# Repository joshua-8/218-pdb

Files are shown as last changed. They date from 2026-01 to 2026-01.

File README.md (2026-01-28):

# archived, moved to https://github.com/SPDLDaemon/SPDL-PDB

# Smart Product Design Lab - Power Distribution Board v2.1
## features
* 16 JST XH plugs with 3.3v ground and 5 volts
* 8 molex 254 plugs for servos

## user guide image
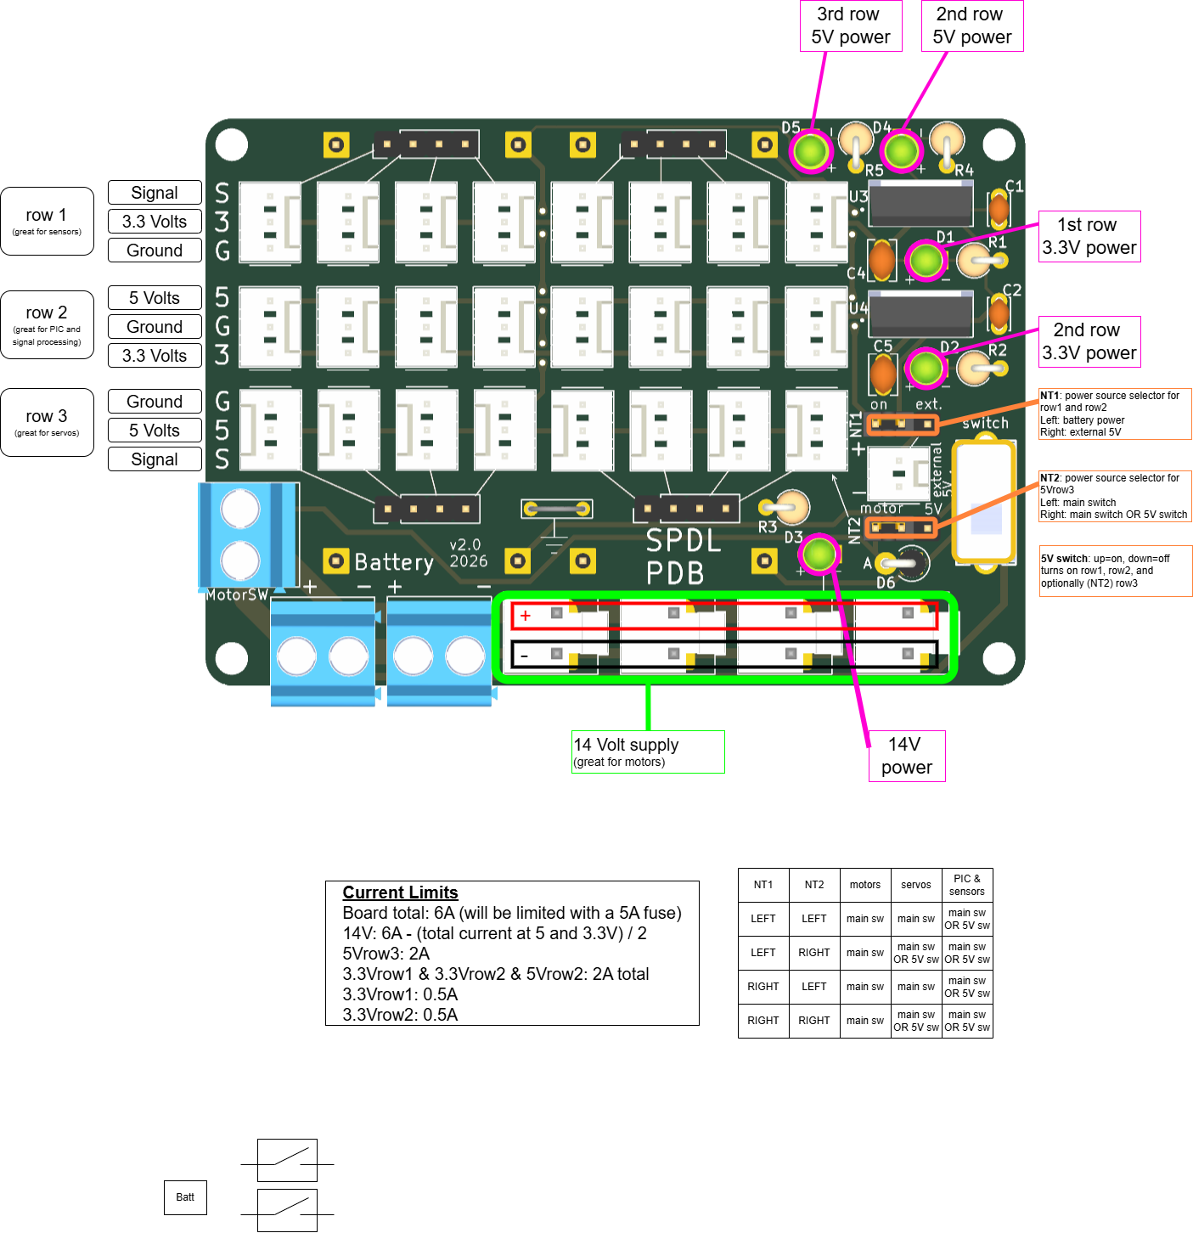
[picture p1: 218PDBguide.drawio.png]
218PDBguide

#### [link to user guide image](/218PDBguide.drawio.png)

### [link to schematic](/schematic.pdf)
### [link to image of PCB traces](/pcb.pdf)

## assembly
assembly guide coming soon

## images
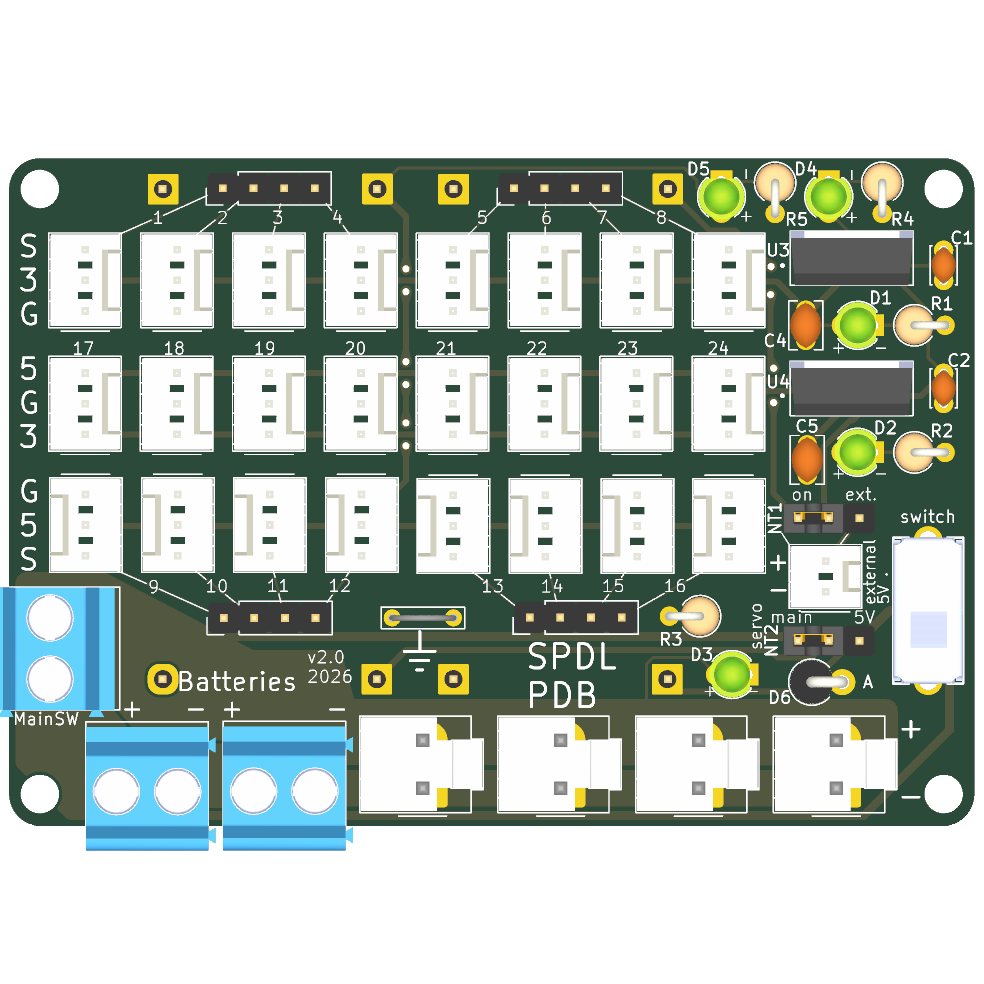
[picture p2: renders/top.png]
render of board

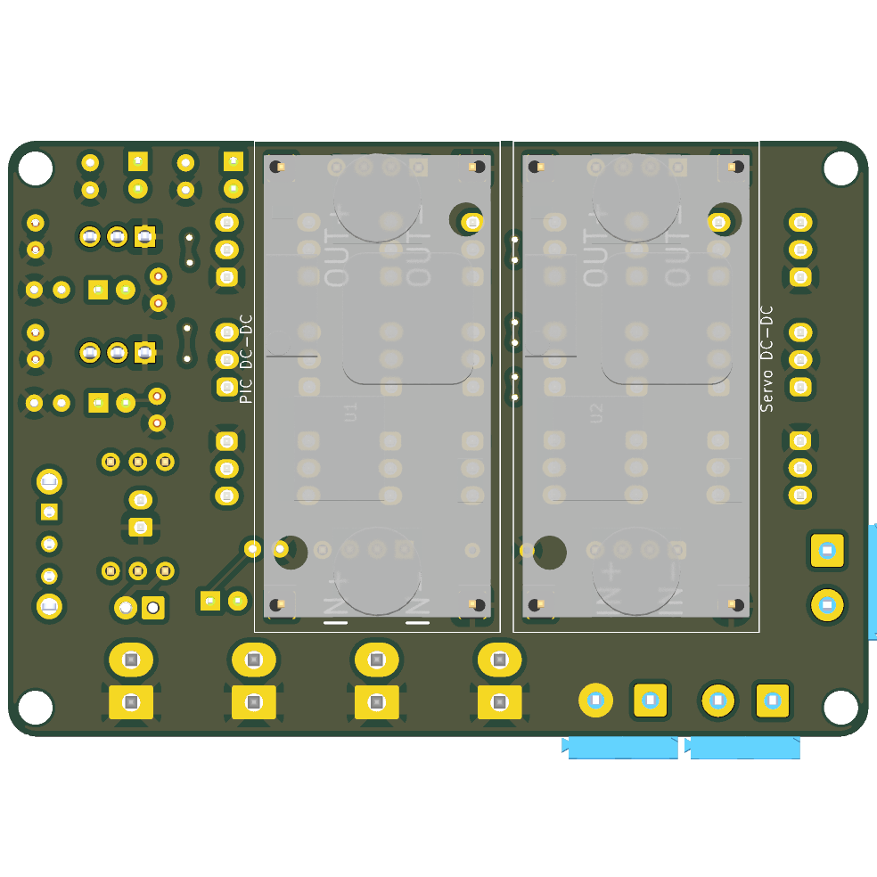
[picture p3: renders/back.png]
render of board back

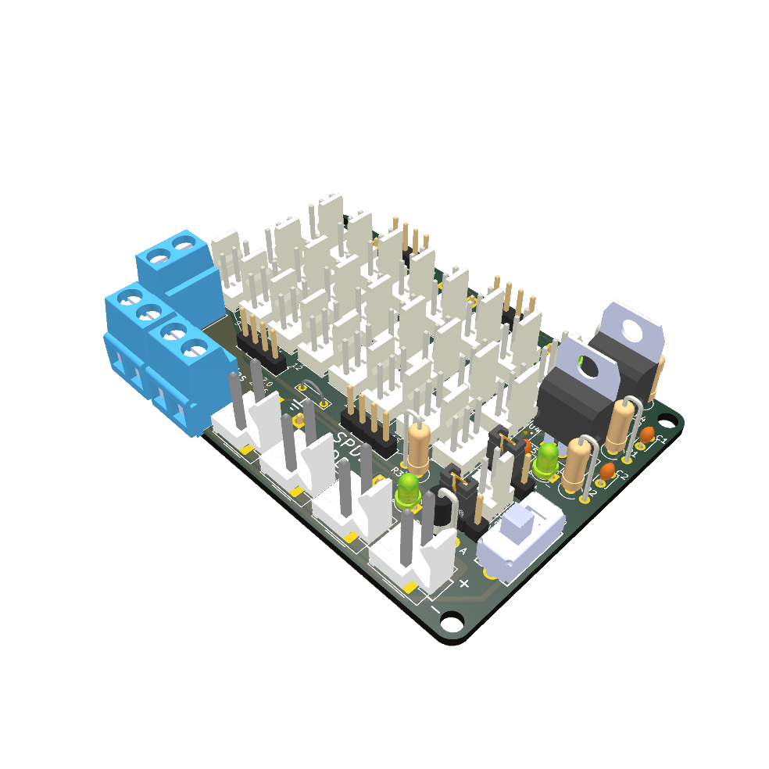
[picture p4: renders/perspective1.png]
render of board perspective1

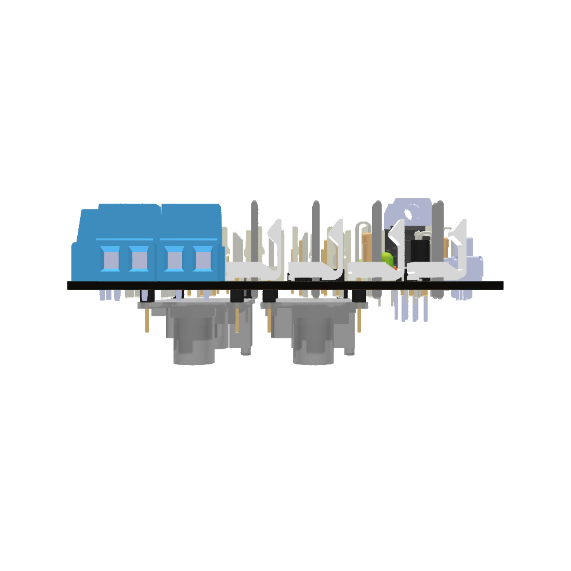
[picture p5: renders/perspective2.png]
render of board perspective2


## buying PCBs and components 
1x set of components from [bill of materials](/BOM.csv)

2x tamiya connectors for batteries (with wires)

1x main power switch

1x fuse holder (with wires) and fuse

1x PCB from ([gerber files](/gerbers.zip))

JST XH sockets (16)

JST XH crimps (48)

small flathead screwdriver

JST XH crimper

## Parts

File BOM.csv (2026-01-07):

Reference | Value | Footprint | Part_Number | QUANTITY
C1,C2 | 0.1 uF | Capacitor_THT:C_Disc_D3.0mm_W2.0mm_P2.50mm | 0.1 uF ceramic capacitor | 2
C4,C5 | 10 uF | Capacitor_THT:C_Disc_D3.8mm_W2.6mm_P2.50mm | 10uF tantalum (polarized) capacitor | 2
D1-D5 | LED | 218-pdb:LED_D3.0mm | 3 mm diameter LED | 5
D6 | diode, >=2 Amp | Diode_THT:D_DO-15_P2.54mm_Vertical_AnodeUp | >=2 Amp diode, e.g. Diotec 1N5060 | 1
FID1,FID2 | jumper | 218-pdb:jumper | pin jumper 0.1" pitch Sullins QPC02SXGN-RC | 2
FID3-FID10 | one header pin | 218-pdb:PinHeader_1x01_P2.54mm_Vertical | spdl, one header pin | 8
J1-J24 | Conn_01x03 | 218-pdb:Molex_KK-254_AE-6410-03A_1x03_P2.54mm_Vertical | 3 pin KK254 molex 0022232031 | 24
J25-J28 | Conn_01x04_Pin | Connector_PinHeader_2.54mm:PinHeader_1x04_P2.54mm_Vertical | 4 header pins 0.1" pitch | 4
J29-J32 | 14 V molex | 218-pdb:Molex_KK-396_A-41791-0002_1x02_P3.96mm_Vertical | 2 pin KK396 molex 0026604020 | 4
J33 | external 5V | 218-pdb:Molex_KK-254_AE-6410-02A_1x02_P2.54mm_Vertical | 2 pin KK 254 molex 0022232021 | 1
J34,J35 | battery | 218-pdb:CUI_TB007-508-02BE | screw terminal, 5.08" pitch, TB007-508-02BE | 2
main1 | MainSW | 218-pdb:CUI_TB007-508-02BE | screw terminal, 5.08" pitch, TB007-508-02BE | 1
NT1,NT2 | ~ | 218-pdb:PinHeader_1x03_P2.54mm_Vertical | 3 header pins 0.1" pitch | 2
R1,R2 | 680 | Resistor_THT:R_Axial_DIN0309_L9.0mm_D3.2mm_P2.54mm_Vertical | spdl | 2
R3 | 3.3k | Resistor_THT:R_Axial_DIN0309_L9.0mm_D3.2mm_P2.54mm_Vertical | spdl | 1
R4,R5 | 1k | Resistor_THT:R_Axial_DIN0309_L9.0mm_D3.2mm_P2.54mm_Vertical | spdl | 2
SW1 | 5V switch | 218-pdb:SLW-12689-4A-N-D | SLW-12689-4A-N-D | 1
TP1 | ground | TestPoint:TestPoint_Bridge_Pitch5.08mm_Drill0.7mm | piece of wire | 1
U1,U2 | DC-DC buck | 218-pdb:HW-411 | HW-411 lm2596 buck converter module | 2
U3,U4 | LD1117V33 | 218-pdb:TO255P1020X450X1968-3 | LD1117V33 | 2

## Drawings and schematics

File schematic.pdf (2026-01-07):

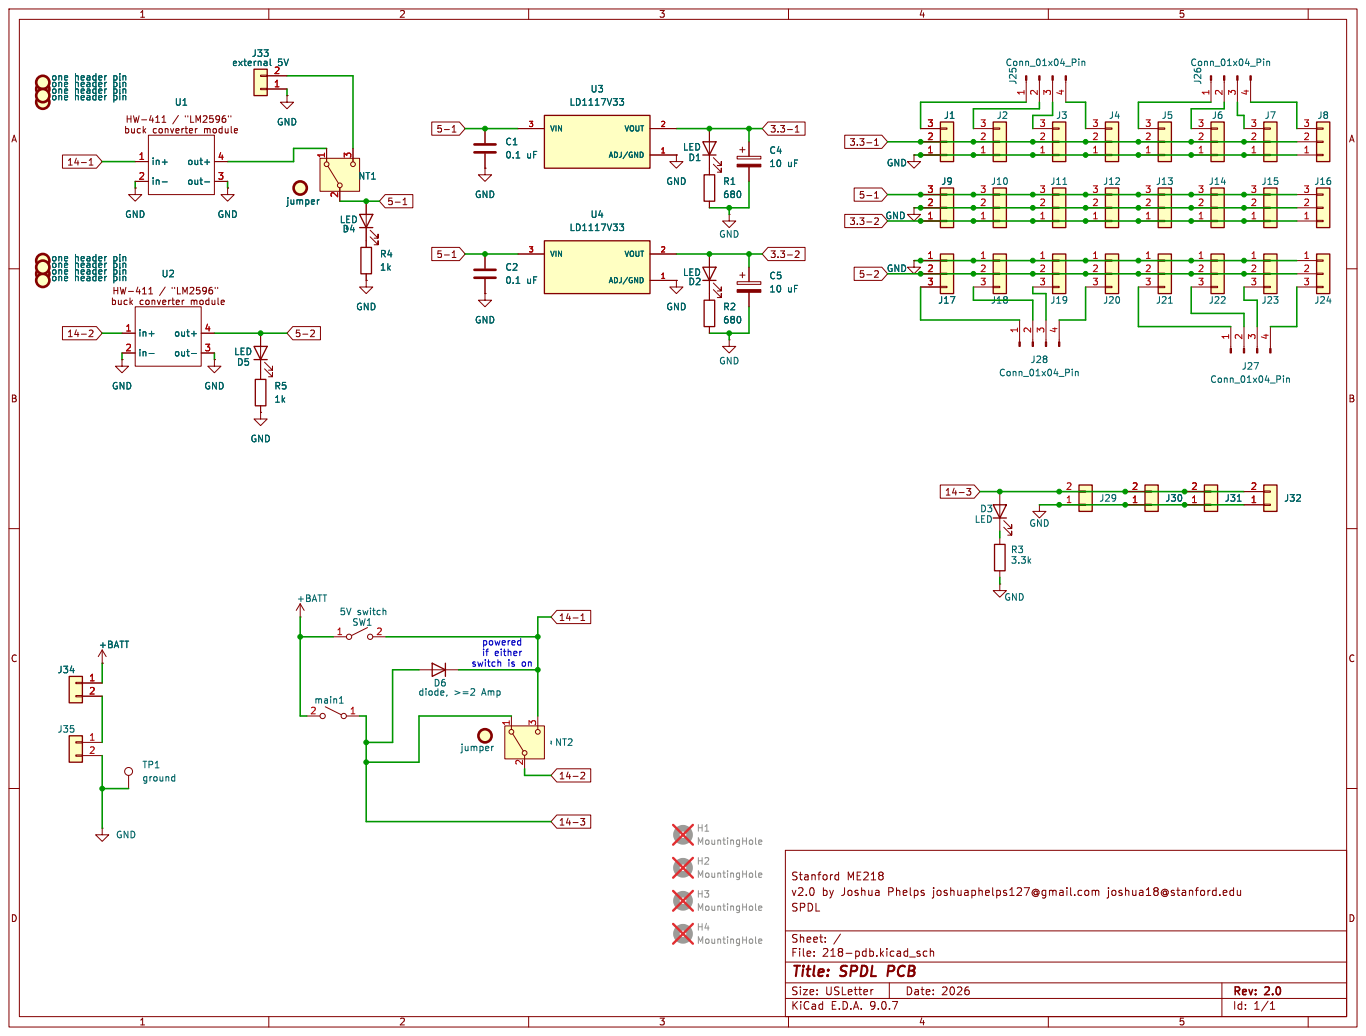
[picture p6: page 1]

powered
if either switch is on

v2.0 by Joshua File: 218-pdb.kicad_sch Sheet: / SPDL | ME218 | | Phelps joshuaphelps127@gmail.com | joshua18@stanford.edu Stanford

E.D.A. 9.0.7 Size: USLetter | | Rev: 2.0 | | | D Date: 2026 KiCad

Id: 1/1 Title: SPDL PCB

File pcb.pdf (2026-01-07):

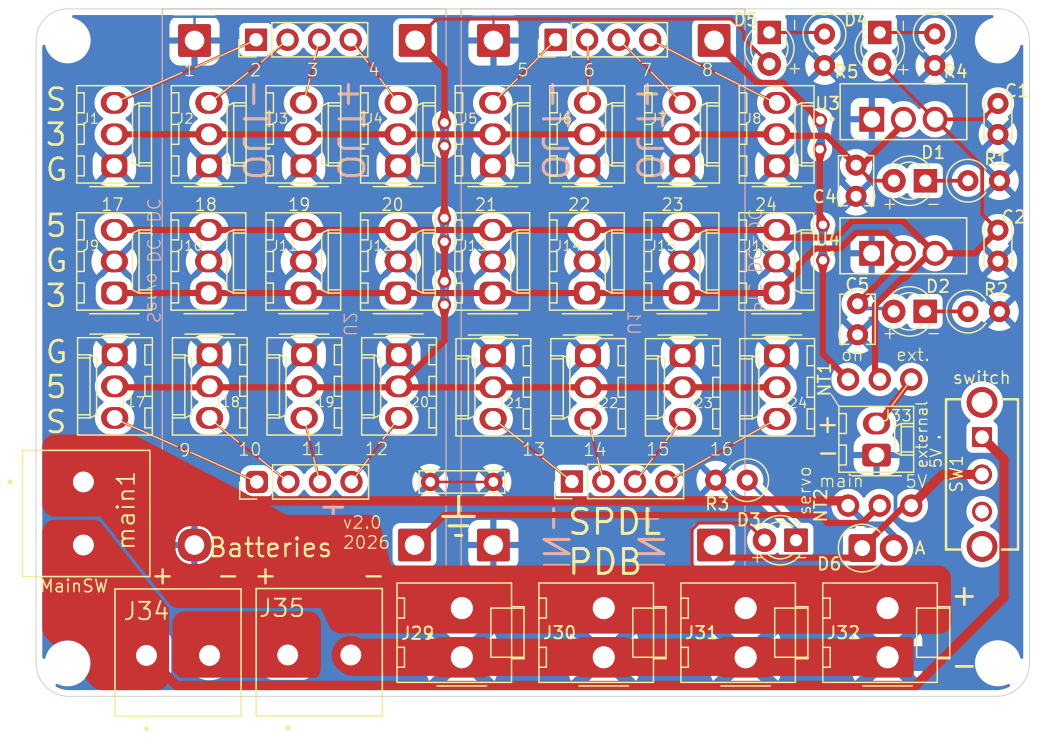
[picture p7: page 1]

PIC DC-DC Servo DC-DC U2 OUT- IN- IN+ OUT+ U1 OUT+ IN- IN+ OUT-

PDB

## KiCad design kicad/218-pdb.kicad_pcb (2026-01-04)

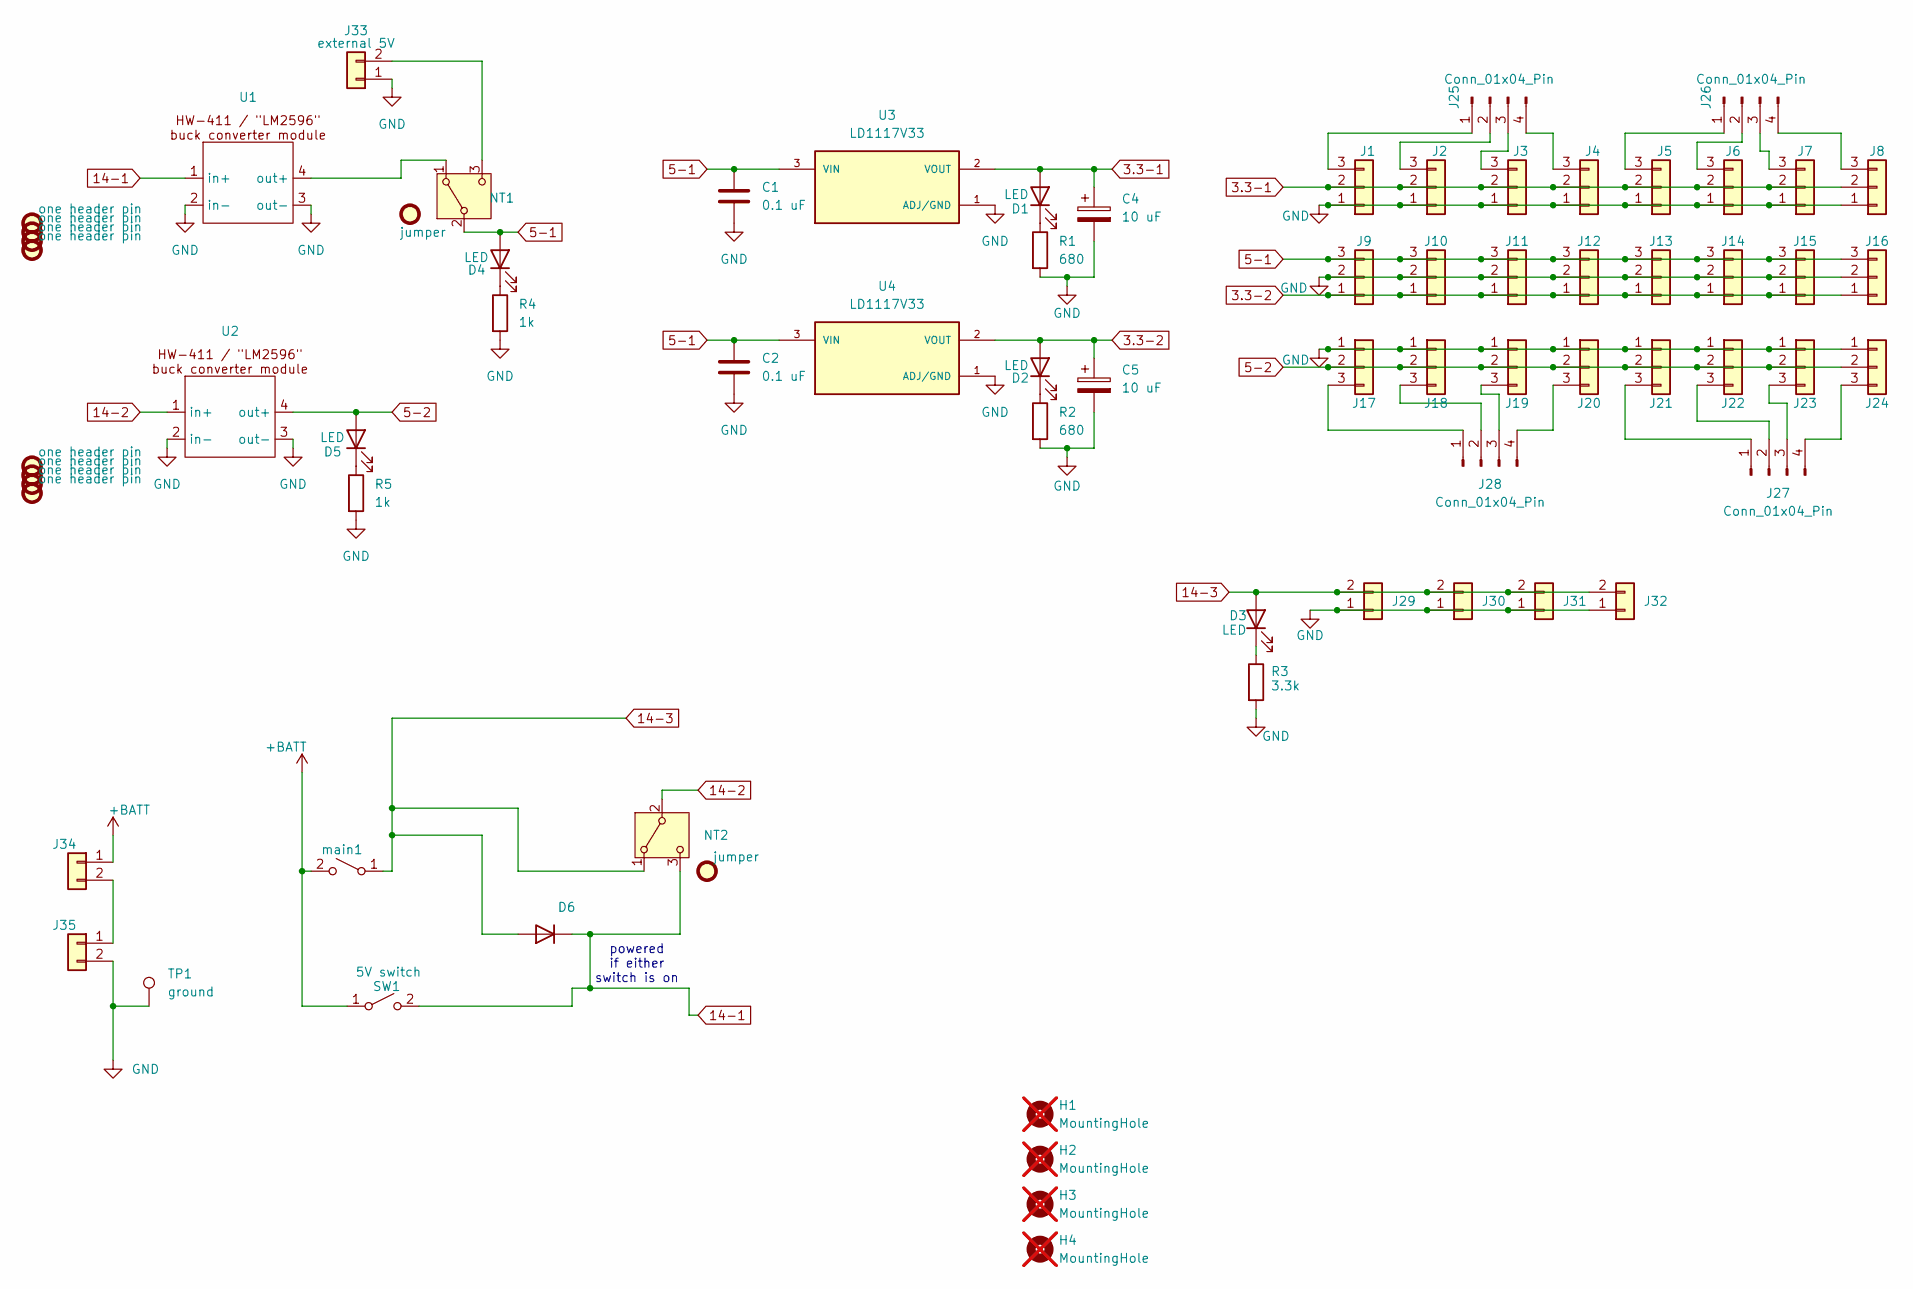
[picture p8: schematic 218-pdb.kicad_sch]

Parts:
C1, C2: 0.1 uF; C_Disc_D3.0mm_W2.0mm_P2.50mm; Part_Number 0.1 uF ceramic capacitor
C4, C5: 10 uF; C_Disc_D3.8mm_W2.6mm_P2.50mm; Part_Number 10uF tantalum (polarized) capacitor
D1, D2, D3, D4, D5: LED; LED_D3.0mm; Part_Number 3 mm diameter LED
D6: diode, >=1Amp; D_DO-41_SOD81_P2.54mm_Vertical_AnodeUp; Part_Number spdl, 1N4935
FID1, FID2: jumper; Part_Number pin jumper 0.1" pitch Sullins QPC02SXGN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
FID3, FID4, FID5, FID6, FID7, FID8, FID9, FID10: one header pin; PinHeader_1x01_P2.54mm_Vertical; Part_Number spdl, one header pin
H1, H2, H3, H4: MountingHole; MountingHole_3.2mm_M3_ISO7380; not fitted
J1, J2, J3, J4, J5, J6, J7, J8, J9, J10, J11, J12, J13, J14, J15, J16, J17, J18, J19, J20, J21, J22, J23, J24: Conn_01x03; Molex_KK-254_AE-6410-03A_1x03_P2.54mm_Vertical; Part_Number 3 pin KK254 molex 0022232031
J25, J26, J27, J28: Conn_01x04_Pin; PinHeader_1x04_P2.54mm_Vertical; Part_Number 4 header pins 0.1" pitch
J29, J30, J31, J32: 14 V molex; Molex_KK-396_A-41791-0002_1x02_P3.96mm_Vertical; Part_Number 2 pin KK396 molex 0026604020
J33: external 5V; Molex_KK-254_AE-6410-02A_1x02_P2.54mm_Vertical; Part_Number 2 pin KK 254 molex 0022232021
J34, J35: battery; CUI_TB007-508-02BE; Part_Number screw terminal, 5.08" pitch, TB007-508-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
NT1, NT2: PinHeader_1x03_P2.54mm_Vertical; Part_Number 3 header pins 0.1" pitch
R1, R2: 680; R_Axial_DIN0309_L9.0mm_D3.2mm_P2.54mm_Vertical; Part_Number spdl; digikey_part_number n/a
R3: 3.3k; R_Axial_DIN0309_L9.0mm_D3.2mm_P2.54mm_Vertical; Part_Number spdl; digikey_part_number n/a
R4, R5: 1k; R_Axial_DIN0309_L9.0mm_D3.2mm_P2.54mm_Vertical; Part_Number spdl; digikey_part_number n/a
SW1: 5V switch; SLW-12689-4A-N-D; Part_Number SLW-12689-4A-N-D
TP1: ground; TestPoint_Bridge_Pitch5.08mm_Drill0.7mm; Part_Number piece of wire
U1, U2: DC-DC buck; HW-411; Part_Number HW-411 lm2596 buck converter module; digikey_part_number n/a
U3, U4: LD1117V33; TO255P1020X450X1968-3; PARTREV 37; DigiKey_Part_Number 497-1491-5-ND
main1: MotorSW; CUI_TB007-508-02BE; Part_Number screw terminal, 5.08" pitch, TB007-508-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

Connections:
3.3-1: C4.1, D1.2 (A), J1.2, J2.2, J3.2, J4.2, J5.2, J6.2, J7.2, J8.2, U3.2 (VOUT)
3.3-2: C5.1, D2.2 (A), J9.1, J10.1, J11.1, J12.1, J13.1, J14.1, J15.1, J16.1, U4.2 (VOUT)
5-1: C1.1, C2.1, D4.2 (A), J9.3, J10.3, J11.3, J12.3, J13.3, J14.3, J15.3, J16.3, NT1.2 (B), U3.3 (VIN), U4.3 (VIN)
5-2: D5.2 (A), J17.2, J18.2, J19.2, J20.2, J21.2, J22.2, J23.2, J24.2, U2.4 (out+)
14-1: D6.1 (K), NT2.3 (C), SW1.2 (B), U1.1 (in+)
14-2: NT2.2 (B), U2.1 (in+)
14-3: D3.2 (A), D6.2 (A), J29.2, J30.2, J31.2, J32.2, NT2.1 (A), main1.1 (A)
+BATT: J34.1, SW1.1 (A), main1.2 (B)
GND: C1.2, C2.2, C4.2, C5.2, J1.1, J2.1, J3.1, J4.1, J5.1, J6.1, J7.1, J8.1, J9.2, J10.2, J11.2, J12.2, J13.2, J14.2, J15.2, J16.2, J17.1, J18.1, J19.1, J20.1, J21.1, J22.1, J23.1, J24.1, J29.1, J30.1, J31.1, J32.1, J33.1, J35.2, R1.2, R2.2, R3.2, R4.2, R5.2, TP1.1, U1.2 (in-), U1.3 (out-), U2.2 (in-), U2.3 (out-), U3.1 (ADJ/GND), U4.1 (ADJ/GND)
unnamed: D1.1 (K), R1.1
unnamed: D2.1 (K), R2.1
unnamed: D3.1 (K), R3.1
unnamed: D4.1 (K), R4.1
unnamed: D5.1 (K), R5.1
unnamed: J1.3, J25.1
unnamed: J2.3, J25.2
unnamed: J17.3, J28.1
unnamed: J18.3, J28.2
unnamed: J19.3, J28.3
unnamed: J20.3, J28.4
unnamed: J21.3, J27.1
unnamed: J22.3, J27.2
unnamed: J23.3, J27.3
unnamed: J24.3, J27.4
unnamed: J3.3, J25.3
unnamed: J4.3, J25.4
unnamed: J5.3, J26.1
unnamed: J6.3, J26.2
unnamed: J7.3, J26.3
unnamed: J8.3, J26.4
unnamed: J33.2, NT1.3 (C)
unnamed: J34.2, J35.1
unnamed: NT1.1 (A), U1.4 (out+)

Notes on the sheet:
powered if either switch is on

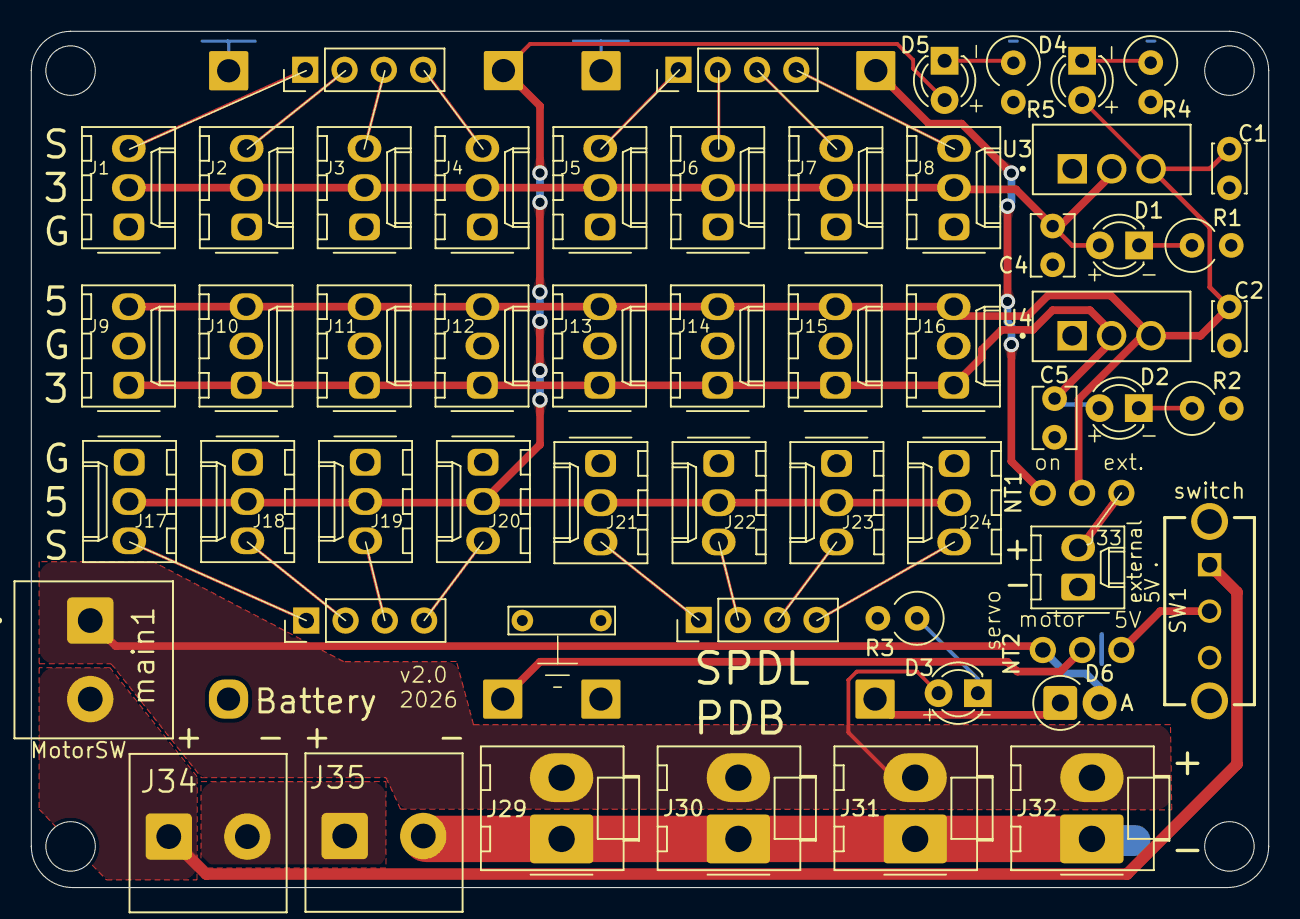
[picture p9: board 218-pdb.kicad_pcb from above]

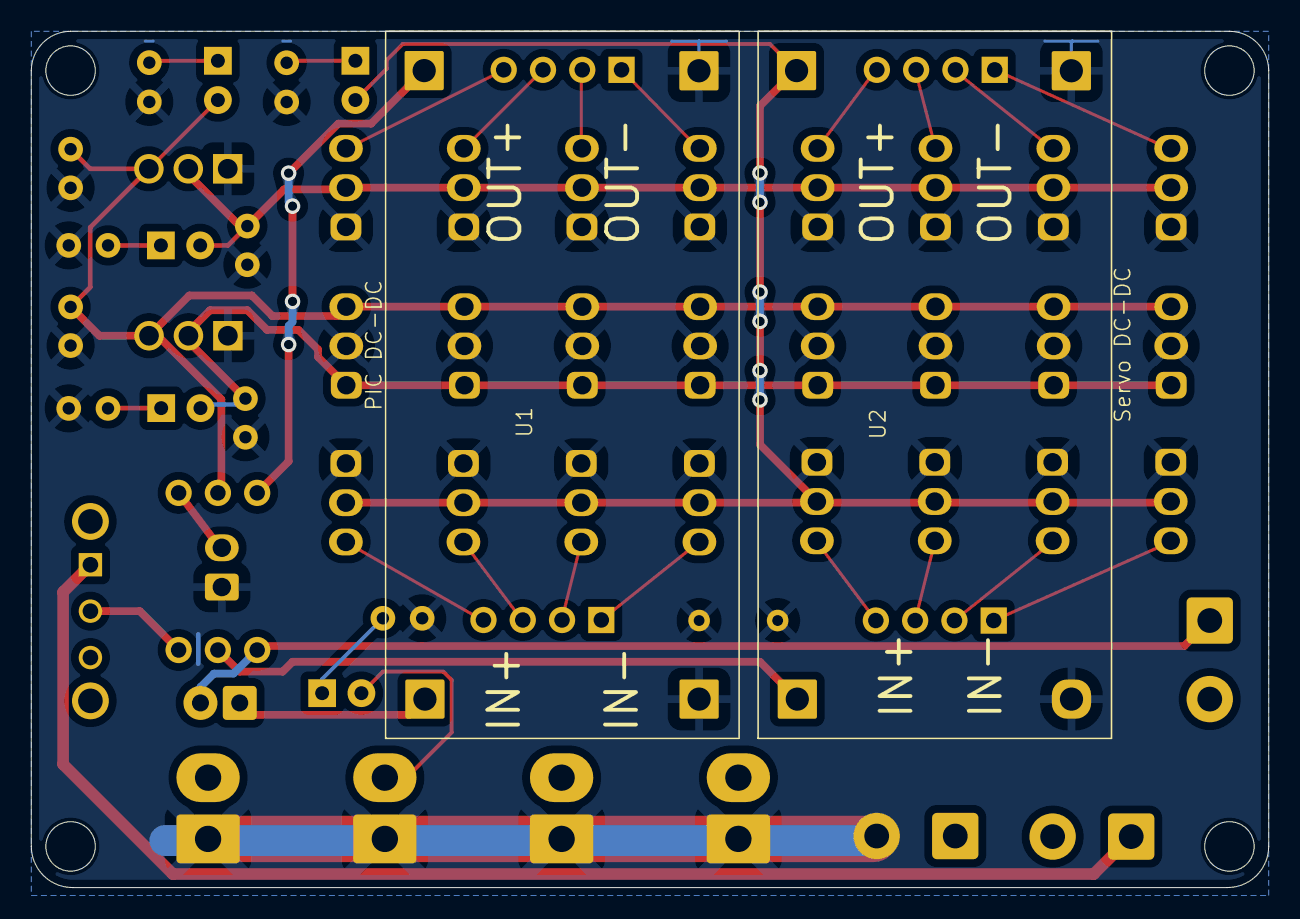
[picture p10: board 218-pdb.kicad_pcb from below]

Board: 2 copper layers, 80.0 x 55.4 mm, 73 parts (10 on the bottom side), 33 nets.

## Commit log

2026-01-01 edit schematic
    [218-pdb.kicad_sch]
2026-01-01 BOT process kicad
    [BOM.csv]
2026-01-02 draw traces, design B
    [218-pdb.kicad_pcb, 218-pdb.kicad_sch]
2026-01-03 update script
    [218-pdb.kicad_pcb, 218-pdb.kicad_sch]
2026-01-04 improve power traces
    [218-pdb.kicad_pcb]
